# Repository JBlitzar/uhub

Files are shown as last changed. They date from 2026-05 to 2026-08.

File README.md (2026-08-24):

# uhub

> [!NOTE]
> uhh so the ports are very close together, which means for some thick USB connectors, plugging in to ports that are next to each other won't work. You might want to space them out if youre going to fab this yourself. Or, you know, just live with it and use skinny connectors.

## Finished product

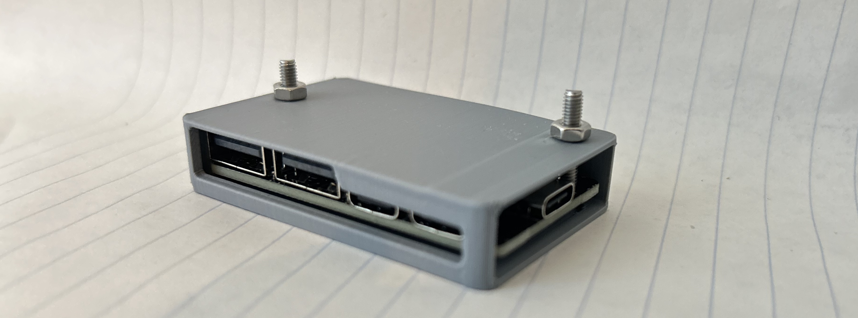
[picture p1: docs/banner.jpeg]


## other pictures

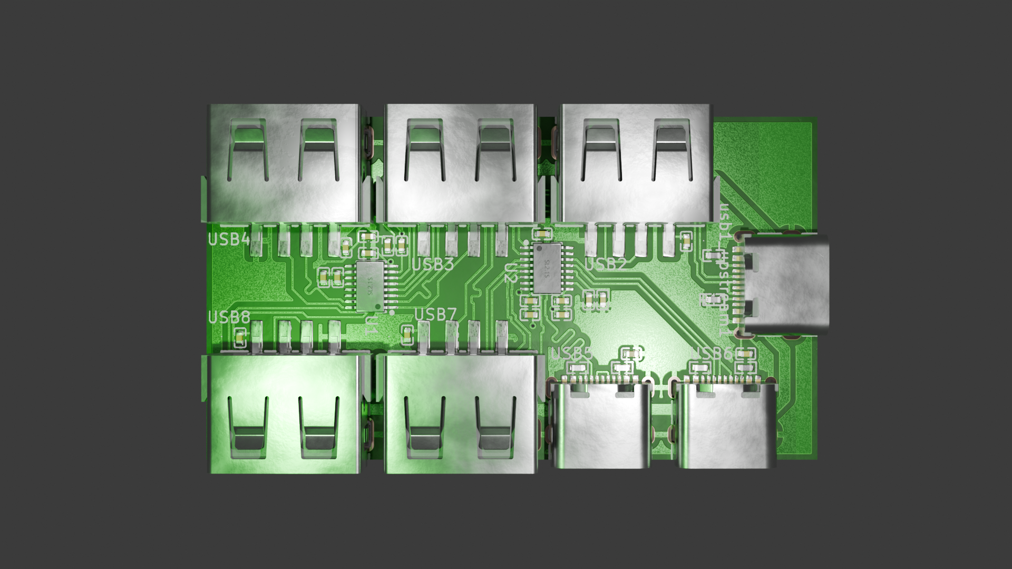
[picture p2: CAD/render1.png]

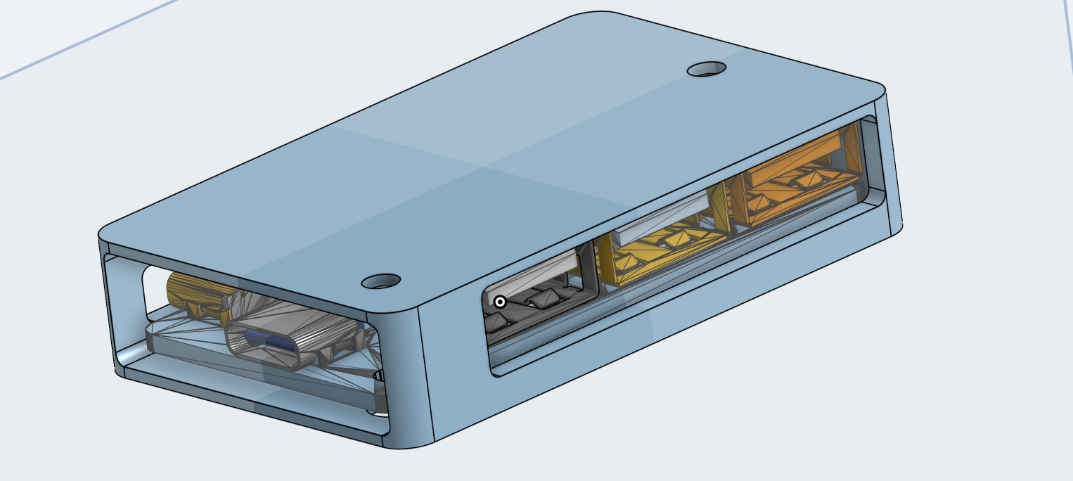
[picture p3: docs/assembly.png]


## What this project is and why I made it

It's a USB hub. It has one upstream USB-C port, and seven downstream ports: Five USB-A and two USB-C. Since the ICs only support four downstream ports, I daisy-chained two of them.

I wanted to make it to connect to more accessories at a time, for use either on my laptop or with my raspberry pi. I also wanted to make it to level up my PCB design skills, after making a macropad. The routing was considerably more difficult, because there a lot more considerations to be made regarding impedance et al.

## PCB Images

[KiCanvas](https://kicanvas.org/?repo=https%3A%2F%2Fgithub.com%2FJBlitzar%2Fuhub%2Ftree%2Fmain%2FPCB%2Fusbhub)

For-fun PCB plot, kicad screenshots below.



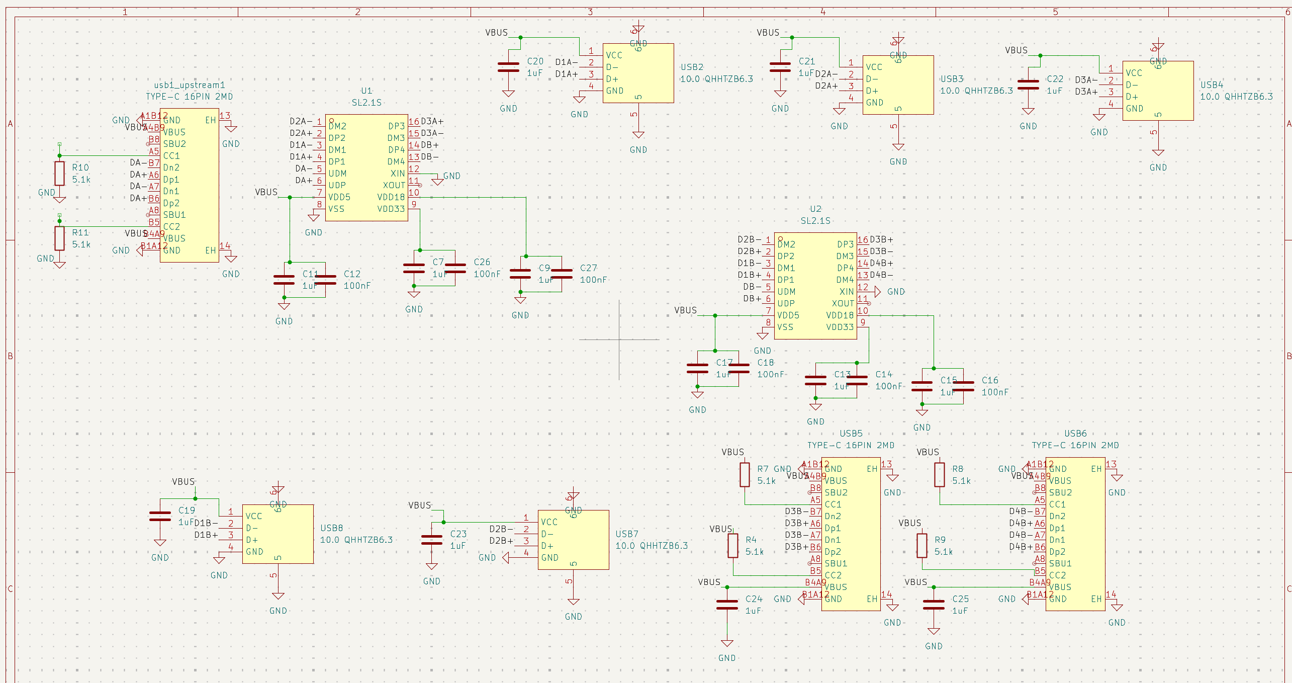
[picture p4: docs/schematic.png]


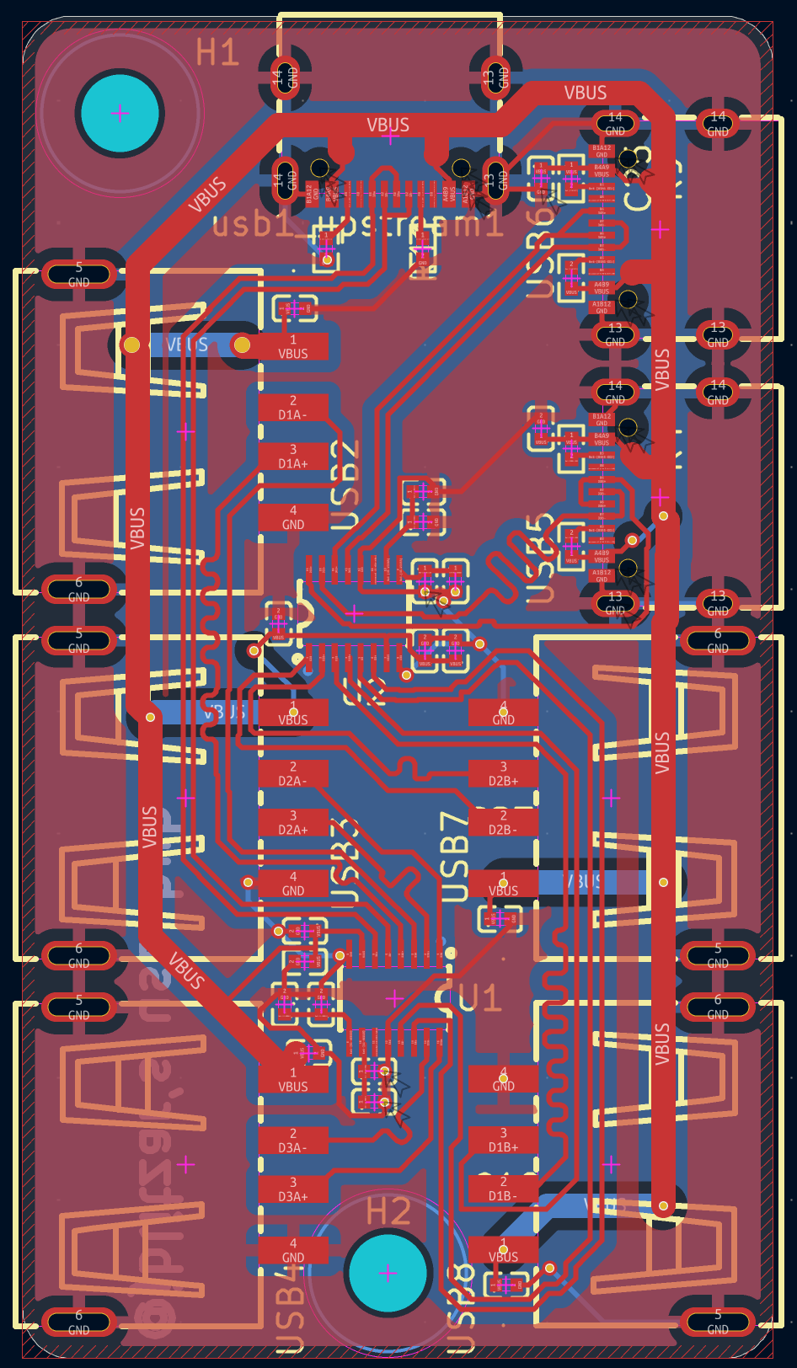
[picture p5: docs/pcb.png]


## Credits

USB Hub Guide: https://rudymakes.com/blog/usb-hub/

I'd like to credit this guide, since I used it as reference, but my design is distinct and my own.

## Bom in table format

| Name | Link | Footprint | Quantity | Value | LCSC Part # | Designator | Distributor  | Total cost |
| --- | --- | --- | --- | --- | --- | --- | --- | --- |
| 1uF capacitor | https://www.lcsc.com/product-detail/C29266.html | C0402 | 13 | 1uF | C29266 | C11, C13, C15, C17, C19, C20, C21, C22, C23, C24, C25, C7, C9 | LCSC | 0 |
| 100nF capacitor | https://www.lcsc.com/product-detail/C60474.html | C0402 | 6 | 100nF | C60474 | C12, C14, C16, C18, C26, C27 | LCSC | 0 |
| 5.1k resistor | https://www.lcsc.com/product-detail/C105872.html  | R0402 | 6 | 5.1k | C105872 | R10, R11, R4, R7, R8, R9 | LCSC | 0 |
| USB IC | https://www.lcsc.com/product-detail/C2684433.html | SSOP-16_L4.6-W2.6-P0.53-LS4.0-BL | 2 | SL2.1S | C2684433 | U1, U2 | LCSC | 0 |
| USB C port | https://www.lcsc.com/product-detail/C2765186.html | USB-C-SMD_TYPE-C-16PIN-2MD-073 | 3 | TYPE-C 16PIN 2MD | C2765186 | USB1_UPSTREAM1, USB5, USB6 | LCSC | 0 |
| USB A port | https://www.lcsc.com/product-detail/C668591.html  | USB-A-TH_10.0QHHTZB6.3 | 5 | 10.0 QHHTZB6.3 | C668591 | USB2, USB3, USB4, USB7, USB8 | LCSC | 0 |
| PCB | N/A | N/A | 1 | N/A | N/A | N/A | JLCPCB | 4 |
| PCBA | N/A | N/A | 1 | N/A | N/A | N/A | JLCPCB | 32.78 |
| Shipping | N/A | N/A | 1 | N/A | N/A | N/A | JLCPCB | 3.3 |
| Sales tax | N/A | N/A | 1 | N/A | N/A | N/A | JLCPCB | 4 |
| 3d printed case | N/A | N/A | 1 | N/A | N/A | N/A | self-sourced | 0 |

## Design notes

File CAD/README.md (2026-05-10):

# uhub CAD

## Onshape link

https://cad.onshape.com/documents/87b669a55093915e8ca520ed/w/a52373a5244fc848afebad15/e/9768ae2d3962627443039482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

## Files

- usbhub_assembly.step: The complete assembly, including the hub and the case.
- usbhub_case.step: The case alone, without the hub.
- uhub_pcb.stl: Just the PCB
- _.blend, _.pcb3d: Files for renders of the PCB.

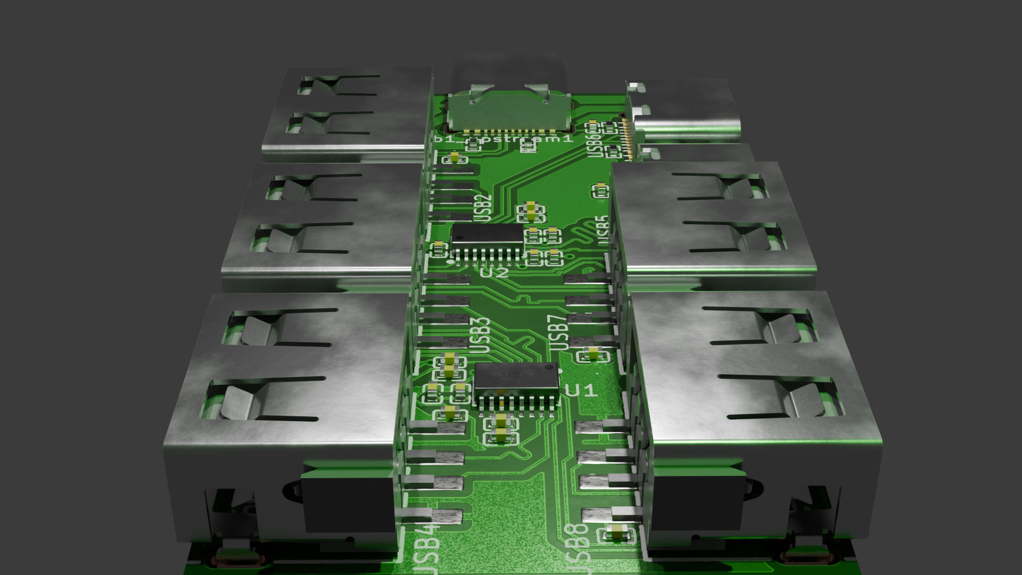
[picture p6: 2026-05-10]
CAD/render2.png

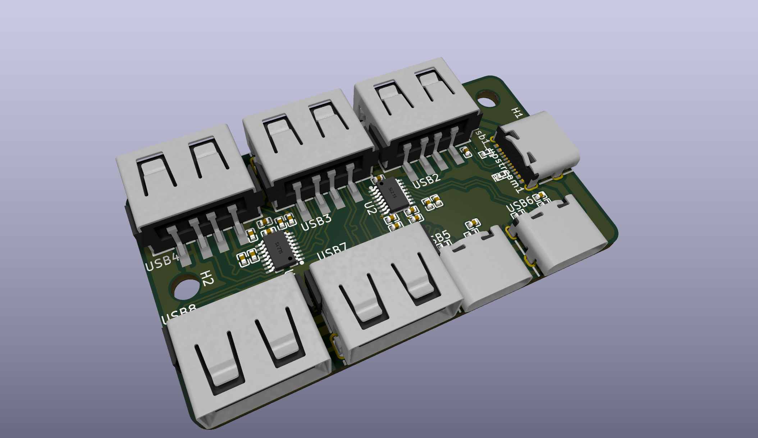
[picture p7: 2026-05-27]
CAD/pcb_kicad_render.png

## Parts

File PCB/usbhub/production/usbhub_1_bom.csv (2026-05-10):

Designator | Footprint | Quantity | Value | LCSC Part #
C11, C13, C15, C17, C19, C20, C21, C22, C23, C24, C25, C7, C9 | C0402 | 13 | 1uF | C29266
C12, C14, C16, C18, C26, C27 | C0402 | 6 | 100nF | C60474
R10, R11, R4, R7, R8, R9 | R0402 | 6 | 5.1k | C105872
U1, U2 | SSOP-16_L4.6-W2.6-P0.53-LS4.0-BL | 2 | SL2.1S | C2684433
USB1_UPSTREAM1, USB5, USB6 | USB-C-SMD_TYPE-C-16PIN-2MD-073 | 3 | TYPE-C 16PIN 2MD | C2765186
USB2, USB3, USB4, USB7, USB8 | USB-A-TH_10.0QHHTZB6.3 | 5 | 10.0 QHHTZB6.3 | C668591

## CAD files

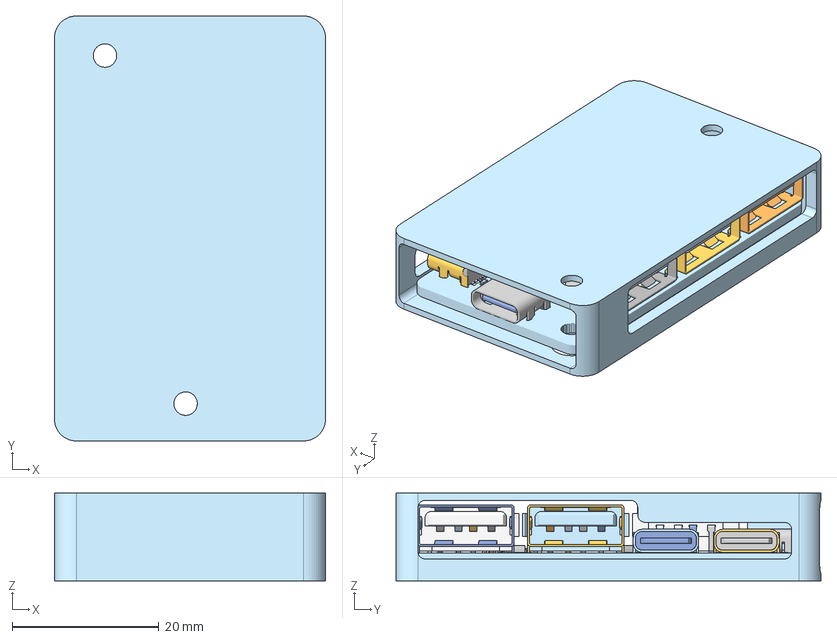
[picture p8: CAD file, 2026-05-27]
CAD/usbhub_assembly.step
37.0 x 58.0 x 12.0 mm

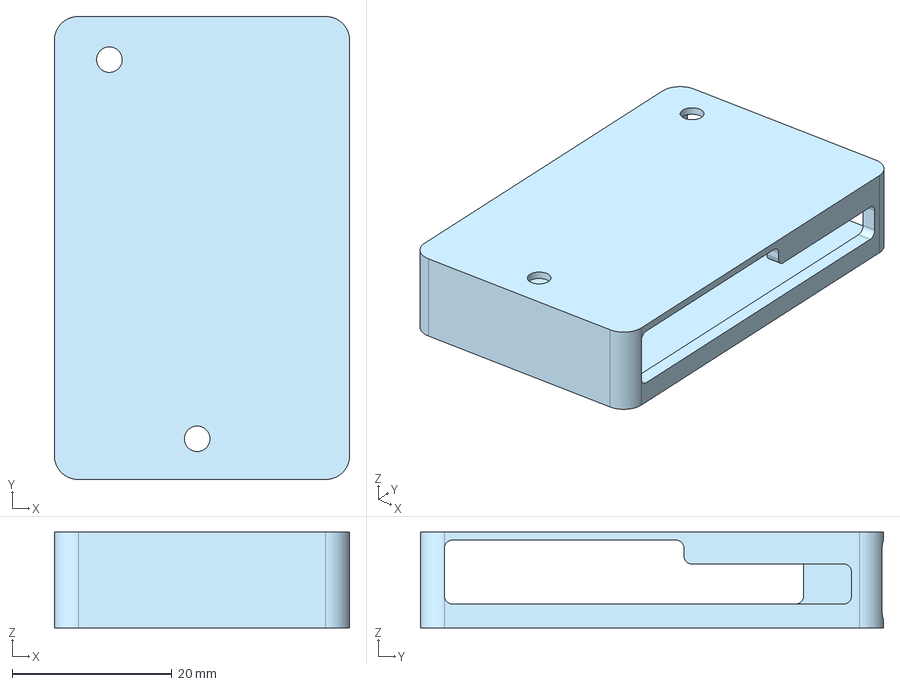
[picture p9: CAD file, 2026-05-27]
CAD/usbhub_case.step
37.0 x 58.0 x 12.0 mm

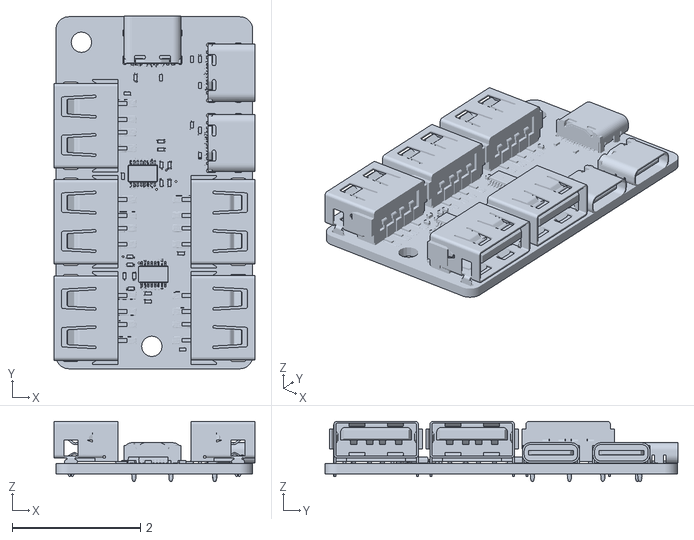
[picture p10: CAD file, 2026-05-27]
CAD/uhub_pcb.stl
3.14 x 5.51 x 0.943

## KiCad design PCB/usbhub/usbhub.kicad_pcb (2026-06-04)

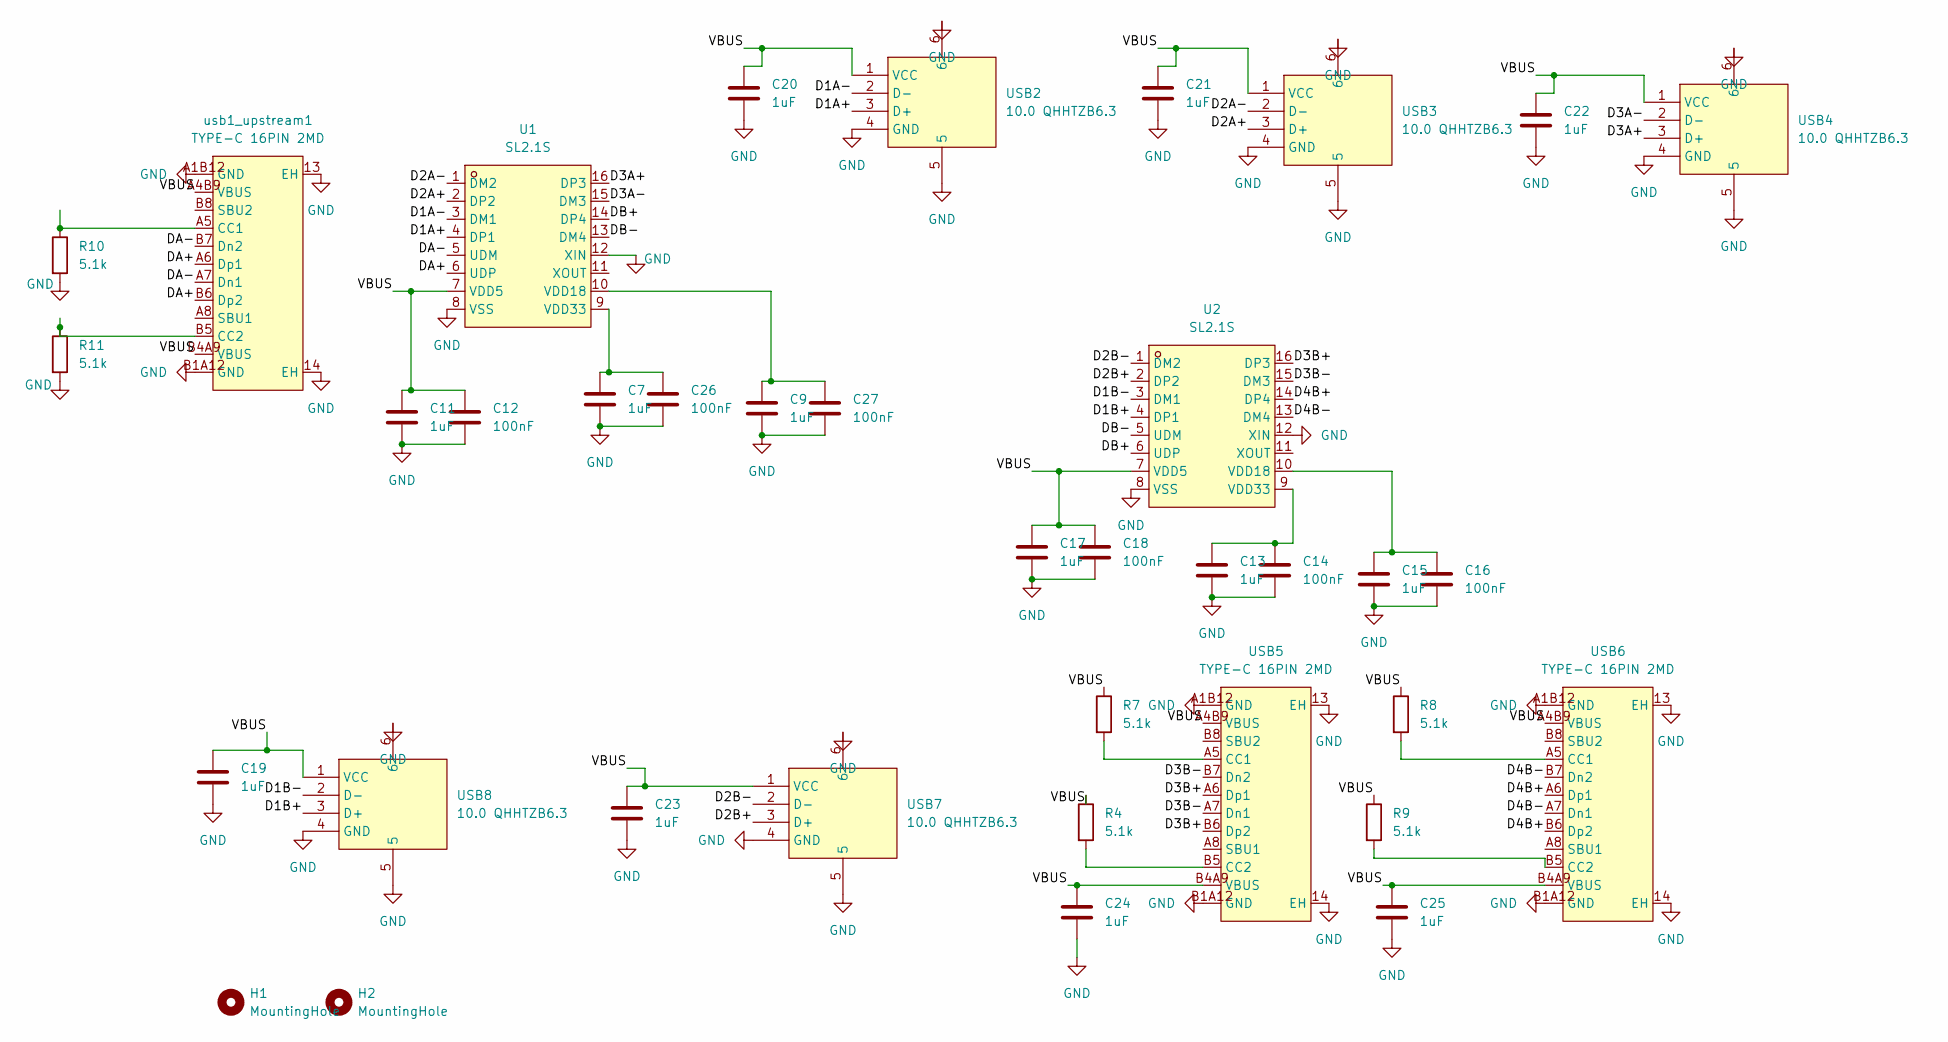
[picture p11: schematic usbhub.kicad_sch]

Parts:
C7, C9, C11, C13, C15, C17, C19, C20, C21, C22, C23, C24, C25: 1uF; C0402; LCSC Part C29266
C12, C14, C16, C18, C26, C27: 100nF; C0402; LCSC Part C60474
H1, H2: MountingHole; MountingHole_3.2mm_M3
R4, R7, R8, R9, R10, R11: 5.1k; R0402; LCSC Part C105872
U1, U2: SL2.1S; SSOP-16_L4.6-W2.6-P0.53-LS4.0-BL; MPN SL2.1s; LCSC Part C2684433
USB2, USB3, USB4, USB7, USB8: 10.0 QHHTZB6.3; USB-A-TH_10.0QHHTZB6.3; MPN 10.0 QHHTZB6.3; LCSC Part C668591
USB5, USB6: TYPE-C 16PIN 2MD; USB-C-SMD_TYPE-C-16PIN-2MD-073; MPN TYPE-C 16PIN 2MD(073); LCSC Part C2765186
usb1_upstream1: TYPE-C 16PIN 2MD; USB-C-SMD_TYPE-C-16PIN-2MD-073; MPN TYPE-C 16PIN 2MD(073); LCSC Part C2765186

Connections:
/D1A+: U1.4 (DP1), USB2.3 (D+)
/D1A-: U1.3 (DM1), USB2.2 (D-)
/D1B+: U2.4 (DP1), USB8.3 (D+)
/D1B-: U2.3 (DM1), USB8.2 (D-)
/D2A+: U1.2 (DP2), USB3.3 (D+)
/D2A-: U1.1 (DM2), USB3.2 (D-)
/D2B+: U2.2 (DP2), USB7.3 (D+)
/D2B-: U2.1 (DM2), USB7.2 (D-)
/D3A+: U1.16 (DP3), USB4.3 (D+)
/D3A-: U1.15 (DM3), USB4.2 (D-)
/D3B+: U2.16 (DP3), USB5.A6 (Dp1), USB5.B6 (Dp2)
/D3B-: U2.15 (DM3), USB5.A7 (Dn1), USB5.B7 (Dn2)
/D4B+: U2.14 (DP4), USB6.A6 (Dp1), USB6.B6 (Dp2)
/D4B-: U2.13 (DM4), USB6.A7 (Dn1), USB6.B7 (Dn2)
/DA+: U1.6 (UDP), usb1_upstream1.A6 (Dp1), usb1_upstream1.B6 (Dp2)
/DA-: U1.5 (UDM), usb1_upstream1.A7 (Dn1), usb1_upstream1.B7 (Dn2)
/DB+: U1.14 (DP4), U2.6 (UDP)
/DB-: U1.13 (DM4), U2.5 (UDM)
/VBUS: C11.1, C12.1, C17.1, C18.1, C19.1, C20.1, C21.1, C22.1, C23.1, C24.1, C25.1, R4.1, R7.1, R8.1, R9.1, U1.7 (VDD5), U2.7 (VDD5), USB2.1 (VCC), USB3.1 (VCC), USB4.1 (VCC), USB5.A4B9 (VBUS), USB5.B4A9 (VBUS), USB6.A4B9 (VBUS), USB6.B4A9 (VBUS), USB7.1 (VCC), USB8.1 (VCC), usb1_upstream1.A4B9 (VBUS), usb1_upstream1.B4A9 (VBUS)
GND: C7.2, C9.2, C11.2, C12.2, C13.2, C14.2, C15.2, C16.2, C17.2, C18.2, C19.2, C20.2, C21.2, C22.2, C23.2, C24.2, C25.2, C26.2, C27.2, R10.2, R11.2, U1.8 (VSS), U1.12 (XIN), U2.8 (VSS), U2.12 (XIN), USB2.4 (GND), USB2.5, USB2.6, USB3.4 (GND), USB3.5, USB3.6, USB4.4 (GND), USB4.5, USB4.6, USB5.13 (EH), USB5.14 (EH), USB5.A1B12 (GND), USB5.B1A12 (GND), USB6.13 (EH), USB6.14 (EH), USB6.A1B12 (GND), USB6.B1A12 (GND), USB7.4 (GND), USB7.5, USB7.6, USB8.4 (GND), USB8.5, USB8.6, usb1_upstream1.13 (EH), usb1_upstream1.14 (EH), usb1_upstream1.A1B12 (GND), usb1_upstream1.B1A12 (GND)
unnamed: C9.1, C27.1, U1.10 (VDD18)
unnamed: C7.1, C26.1, U1.9 (VDD33)
unnamed: C15.1, C16.1, U2.10 (VDD18)
unnamed: C13.1, C14.1, U2.9 (VDD33)
unnamed: R7.2, USB5.A5 (CC1)
unnamed: R4.2, USB5.B5 (CC2)
unnamed: R8.2, USB6.A5 (CC1)
unnamed: R9.2, USB6.B5 (CC2)
unnamed: R10.1, usb1_upstream1.A5 (CC1)
unnamed: R11.1, usb1_upstream1.B5 (CC2)

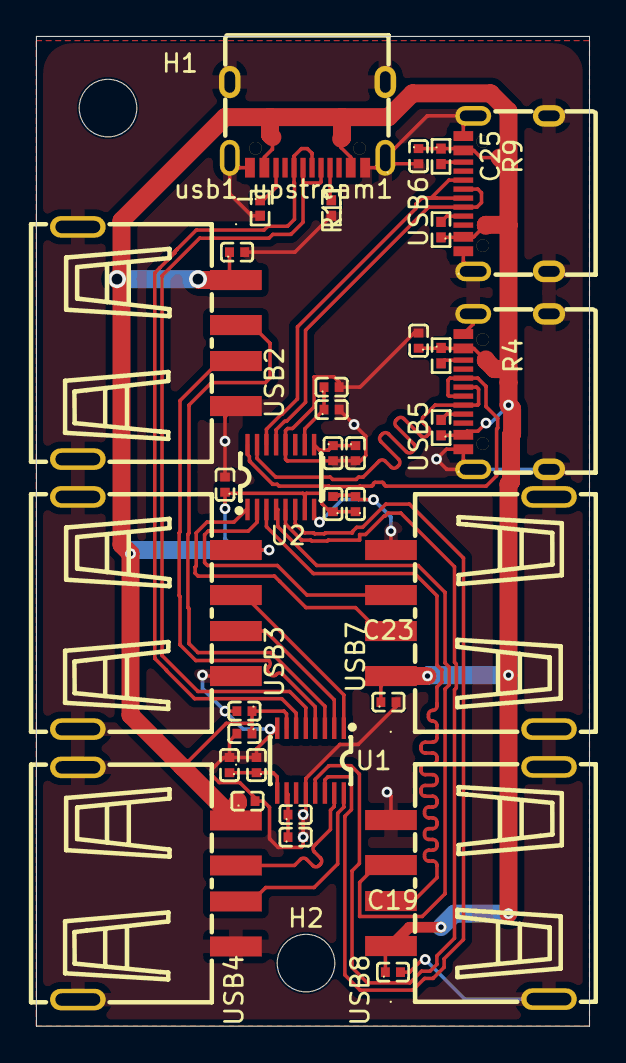
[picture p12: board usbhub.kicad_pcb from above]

Board: 2 copper layers, 30.7 x 55.0 mm, 37 parts (0 on the bottom side), 30 nets.

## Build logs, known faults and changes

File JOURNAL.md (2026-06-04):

# 5/9/2026 8 PM - Researched, made prelim schematic, routed it

_Time spent: 2.883333333333333h_

first journal!!

So I got my idea, which is to make a USB hub. this is useful both for my computer and for the raspberry pi I own, I have lots of usb accessories and this would consolidate ports. To spice things up, I'm daisy-chaining two ICs together. I found a guide that goes through the general steps, but obviously I'm doing my own thing since, you know, I'm using two ICs, using easyeda instead of kicad, and doing it myself.

I got all the footprints imported, and that worked great. I worked on the schematic, and asked for feedback on slack. Everything was correct except I mistook the sbu lines for the cc lines.

Routing's kind of nightmarish because all the data lines need to have no vias, need to be approximately length matched in the differential pairs, and are all on one layer. In the end, I got it done! I am quite proud of my routing. All in just two layers. :)

Only DRC errors after I connected everything were not my fault--corrupted footprints, although hopefully in review they can make sure it's all good.

Anyways, yeah!
Screenshot 2026-05-09 at 8.28.07 PM



Screenshot 2026-05-09 at 8.28.47 PM

# 5/10/2026 9 AM - Made all the traces good

_Time spent: 0.5833333333333334h_

More wiggly traces, should be length-matched and no big distance changes between differential pairs.

I also cleaned up the silkscreen

But mostly I was just fiddling around in kicad. I guess I cleaned up the ground plane. The board itself's mostly done (?) so project work time after this'll probably be making it shipped, and debugging

Screenshot 2026-05-10 at 8.41.43 AM

# 5/10/2026 3 PM - Cadded case, wrote docs, reviewed guidelines

_Time spent: 2h_

I went through all the requirements. I also made a nice case in onshape :)

Now, my repo is properly organized, and the readme walks readers through what the project is. I also made some super cool 3D renders in blender!!



Screenshot 2026-05-10 at 3.23.11 PM

# 5/26/2026 5 PM - Migrated to Forge, added mounting holes, etc

_Time spent: 1.43h_

Stasis review was stagnant for two weeks, I guess the reviewers are busy. I've decided to migrate to Forge. Most of the stuff just copied over. I then did some research about BOM reduction, but I genuinely can't because of the special IC is in the extended parts. It's not too bad anyways, can always pay out of the other grant if I really have to.

I also added mounting holes. I couldn't go for the standard all-four-corners layout because my PCB's pretty packed, but top left corner and bottom middle should be good enough. It's just for securing things in the case. I then added the holes to the case. The plan is to use M3 screws and have a mangement system similar to the Hackpad, where there's a 6mm hole at the bottom to fit the head of the screw, then a 3mm hole in the pcb. This also nicely elevates it from the surface, which is kind of cool. Then the nut will just be screwed in from the top and visible, so just a 3mm hole on the top of the case. No BOM additions needed since I'll just self-source these m3 screws and nuts.

The fact that some traces are inside the courtyard shouldn't be a problem (no 3d components or anything, plus the back, where the screw head's actually going to be, is completely clear). Then again, I'm no pcb expert.

I re-exported twice because I at first did 5mm instead of 6mm for the m3 head, and then I wanted to nitpick some traces.

All this combined genuinely took an hour and a half: I timed when I started. Anyways, there you go.





# 6/3/2026 7 PM - Most traumatic session ordering JLC

_Time spent: 0.1h_

> This took more like 0.5-1 hours, but this of course doesn't count as hardware learning time, so I'm deflating myself here. 

Anyways, I went to upload all my stuff to JLC. And I was clicking through, selecting my various things. Then it's time for PCBA. Now keep in mind
I've never done pcba before, so it was pretty new to me. I uploaded my bom and uploaded my positions csv. One small hiccup that my hole footprints were somehow on the BOM, even though of course they're not a part that I need to place, so I removed them. No biggie. And then I clicked through to the preview, and I was about to just click past and order it. But then I saw that the HUB ICs WERE ROTATED NINETY DEGREES.



So even though I used an automated plugin, "Fabrication Toolkit" to generate these placement files, I edited it manually to do the hub ICs correctly. It really makes you trust the system less when automated tools fail you like this, but hopefully everything else works. The thing with pcba is that it's kind of out of my hands now, which is both good and bad. Now there's one more funny thing, which is that the IC itself is symmetrical but the pins cannot be used interchangably. So I had to go off of the orientation of the etched "SL2.1S" on the Kicad preview to get things to work. Anyways, it looks good now



Here's an artistic rendition of what I went through.

Anyways, we'll see how this turns out! By the way I also printed out my case, but I might make some tweaks to it.

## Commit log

2026-05-09 A preliminary schematic
    [usbhub.kicad_pcb, usbhub.kicad_sch]
2026-05-09 unmixup cc1 with sbu1
    [usbhub.kicad_sch]
2026-05-09 minus/plus rename
    [usbhub.kicad_pcb, usbhub.kicad_sch]
2026-05-09 routing? idk bro
    [usbhub.kicad_pcb]
2026-05-10 route it lwk
    [usbhub.kicad_pcb]
2026-05-10 some skew tweaks
    [usbhub.kicad_pcb]
2026-05-10 length match everything nicer
    [usbhub.kicad_pcb]
2026-05-10 better silkscreen
    [usbhub.kicad_pcb]
2026-05-10 case and assembly
    [usbhub.kicad_pcb, usbhub_case.step]
2026-05-10 new bom
    [BOM.csv]
2026-05-10 Production files
    [usbhub_1_bom.csv, usbhub_1_designators.csv, usbhub_1_positions.csv]
2026-05-27 update all the steps
    [uhub_pcb.stl, usbhub.kicad_pcb, usbhub.kicad_sch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]
2026-05-27 make it 6mm
    [usbhub_assembly.step, usbhub_case.step]
2026-05-27 no curvy trace around nonexistent hole
    [usbhub.kicad_pcb]
2026-05-31 tune skew, eliminate via-in-pad, improve gnd connections
    [usbhub.kicad_pcb]
